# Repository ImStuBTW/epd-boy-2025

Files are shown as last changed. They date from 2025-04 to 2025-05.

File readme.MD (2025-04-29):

# EPD Boy (2025)

A work in progress ePaper laynard charm.

## Preview

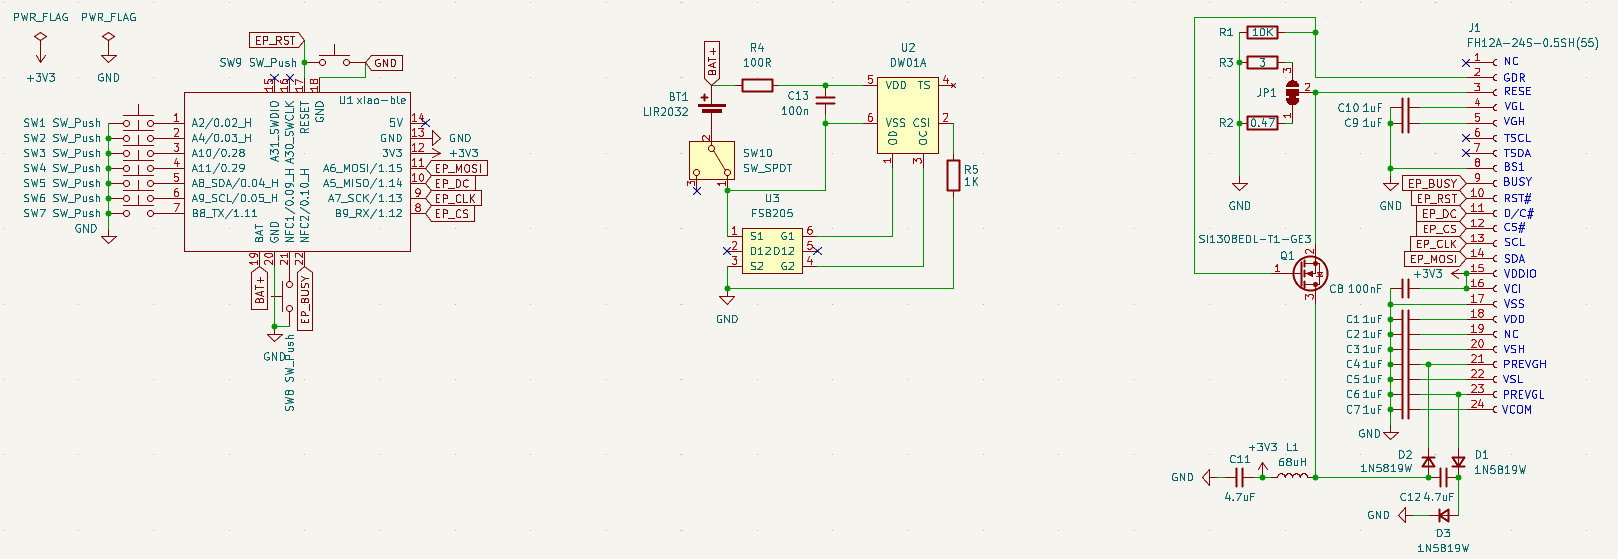
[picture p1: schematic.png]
Schematic

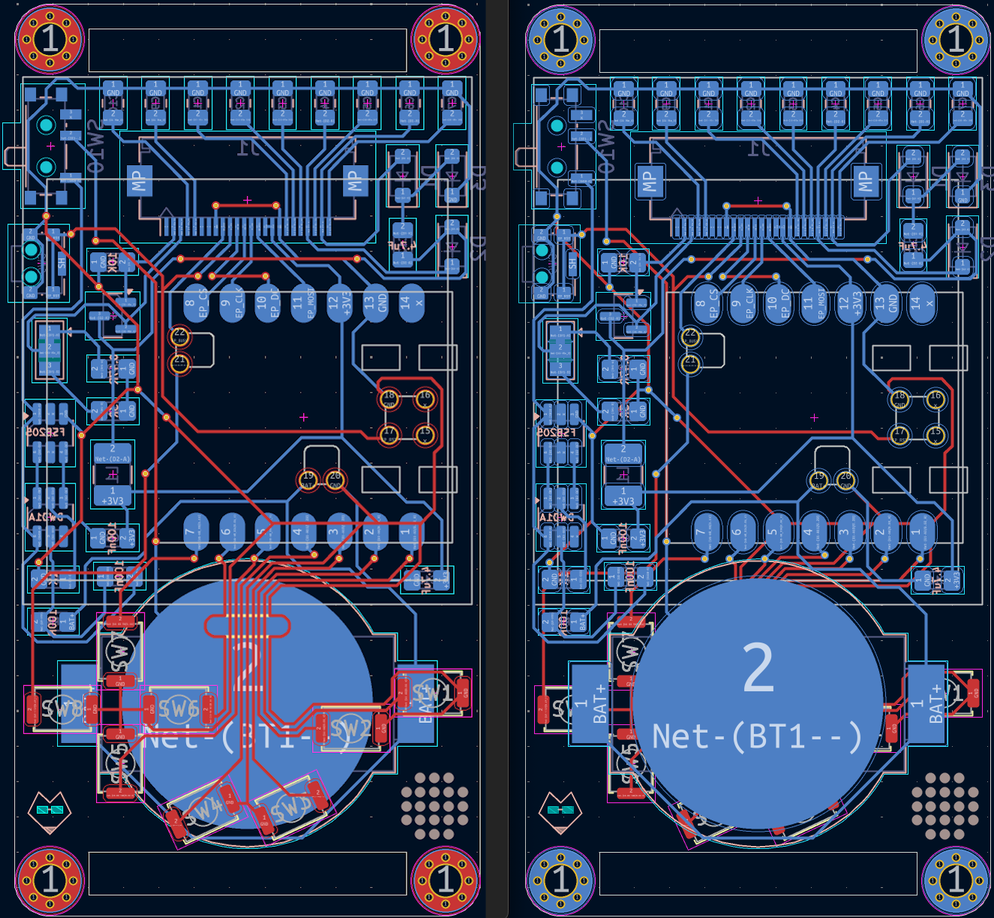
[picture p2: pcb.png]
PCB

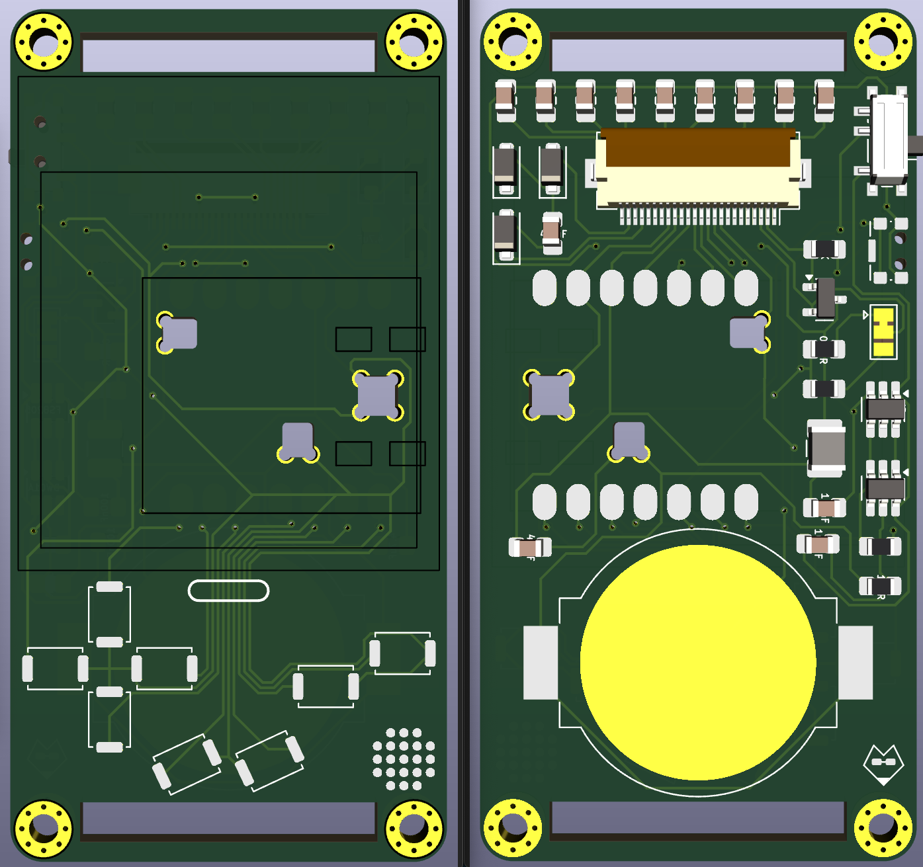
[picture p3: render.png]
Render


## References

Good Display: https://www.good-display.com/product/388.html

E-Ink Adapter: https://hackaday.io/project/164772-e-ink-adapter

Universal ePaper Display: https://www.pcbway.com/project/shareproject/Universal_E_Paper_adapter_PCB_9b9a845c.html

ZMK Design Guide (BMS Circuit Protection): https://github.com/ebastler/zmk-designguide?tab=readme-ov-file#additional-battery-management-considerations

BMS Footprints: https://github.com/ebastler/marbastlib

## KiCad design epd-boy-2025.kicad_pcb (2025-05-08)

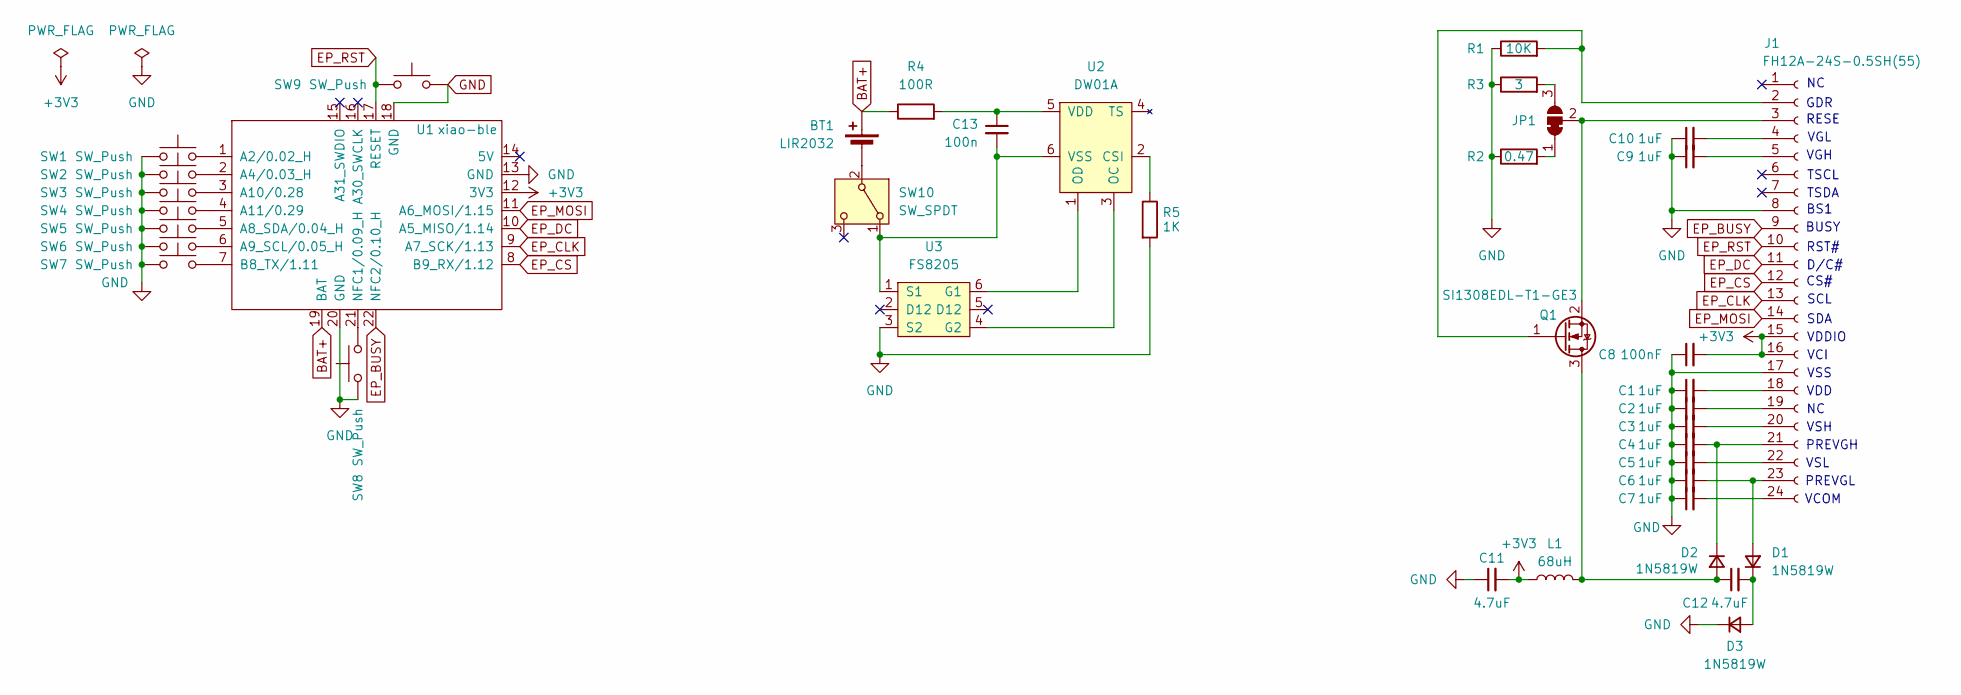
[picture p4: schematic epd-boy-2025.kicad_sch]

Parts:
BT1: LIR2032; BatteryHolder_MPD_BC2003_1x2032
C1, C2, C3, C4, C5, C6, C7, C9, C10: 1uF; C_0805_2012Metric_Pad1.18x1.45mm_HandSolder
C8: 100nF; C_0805_2012Metric_Pad1.18x1.45mm_HandSolder
C11, C12: 4.7uF; C_0805_2012Metric_Pad1.18x1.45mm_HandSolder
C13: 100n; C_0805_2012Metric_Pad1.18x1.45mm_HandSolder
D1, D2, D3: 1N5819W; D_SOD-123F
J1: FH12A-24S-0.5SH(55); Hirose_FH12-24S-0.5SH_1x24-1MP_P0.50mm_Horizontal
JP1: SolderJumper_3_Bridged12; SolderJumper-3_P1.3mm_Bridged12_Pad1.0x1.5mm
L1: 68uH; L_1210_3225Metric_Pad1.42x2.65mm_HandSolder
Q1: SI1308EDL-T1-GE3; SOT-23
R1: 10K; R_0805_2012Metric_Pad1.20x1.40mm_HandSolder
R2: 0.47; R_0805_2012Metric_Pad1.20x1.40mm_HandSolder
R3: 3; R_0805_2012Metric_Pad1.20x1.40mm_HandSolder
R4: 100R; R_0805_2012Metric_Pad1.20x1.40mm_HandSolder
R5: 1K; R_0805_2012Metric_Pad1.20x1.40mm_HandSolder
SW1, SW2, SW3, SW4, SW5, SW6, SW7, SW8: SW_Push; SW_Push_SPST_NO_Alps_SKRK
SW9: SW_Push; SW_SPST_CK_KMS2xxGP
SW10: SW_SPDT; SW_SPDT_PCM12
U1: xiao-ble; xiao-ble-smd-cutout-nfc
U2: DW01A; SOT-23-6_Handsoldering; LCSC C61503
U3: FS8205; SOT-23-6_Handsoldering; LCSC C32254

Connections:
+3V3: C8.2, C11.2, J1.15, J1.16, L1.1, U1.12 (3V3)
BAT+: BT1.1 (+), R4.1, U1.19 (BAT)
EP_BUSY: J1.9, U1.22 (NFC2/0.10_H)
EP_CLK: J1.13, U1.9 (A7_SCK/1.13)
EP_CS: J1.12, U1.8 (B9_RX/1.12)
EP_DC: J1.11, U1.10 (A5_MISO/1.14)
EP_MOSI: J1.14, U1.11 (A6_MOSI/1.15)
EP_RST: J1.10, SW9.1, U1.17 (RESET)
GND: C1.1, C2.1, C3.1, C4.1, C5.1, C6.1, C7.1, C8.1, C9.1, C10.1, C11.1, D3.1 (K), J1.8, J1.17, R1.1, R2.1, R3.1, R5.2, SW1.1, SW2.1, SW3.1, SW4.1, SW5.1, SW6.1, SW7.1, SW8.1, SW9.2, U1.13 (GND), U1.18 (GND), U1.20 (GND), U3.3 (S2)
unnamed: BT1.2 (-), SW10.2 (B)
unnamed: C6.2, D1.2 (A), J1.23
unnamed: C12.2, D1.1 (K), D3.2 (A)
unnamed: C12.1, D2.2 (A), L1.2, Q1.3 (D)
unnamed: C4.2, D2.1 (K), J1.21
unnamed: J1.2, Q1.1 (G), R1.2
unnamed: J1.3, JP1.2 (C), Q1.2 (S)
unnamed: C10.2, J1.4
unnamed: C9.2, J1.5
unnamed: C1.2, J1.18
unnamed: C2.2, J1.19
unnamed: C3.2, J1.20
unnamed: C5.2, J1.22
unnamed: C7.2, J1.24
unnamed: JP1.1 (A), R2.2
unnamed: JP1.3 (B), R3.2
unnamed: C13.2, SW10.1 (A), U2.6 (VSS), U3.1 (S1)
unnamed: SW1.2, U1.1 (A2/0.02_H)
unnamed: SW2.2, U1.2 (A4/0.03_H)
unnamed: SW5.2, U1.5 (A8_SDA/0.04_H)
unnamed: SW6.2, U1.6 (A9_SCL/0.05_H)
unnamed: SW3.2, U1.3 (A10/0.28)
unnamed: SW4.2, U1.4 (A11/0.29)
unnamed: SW7.2, U1.7 (B8_TX/1.11)
unnamed: SW8.2, U1.21 (NFC1/0.09_H)
unnamed: R5.1, U2.2 (CSI)
unnamed: U2.3 (OC), U3.4 (G2)
unnamed: U2.1 (OD), U3.6 (G1)
unnamed: C13.1, R4.2, U2.5 (VDD)

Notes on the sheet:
BS1
VCI
VSS
SCL
VCOM
VSL
BUSY
PREVGL
TSDA
D/C#
SDA
VDDIO
RST#
VGL
GDR
CS#
TSCL
PREVGH
VSH
RESE
VDD
VGH

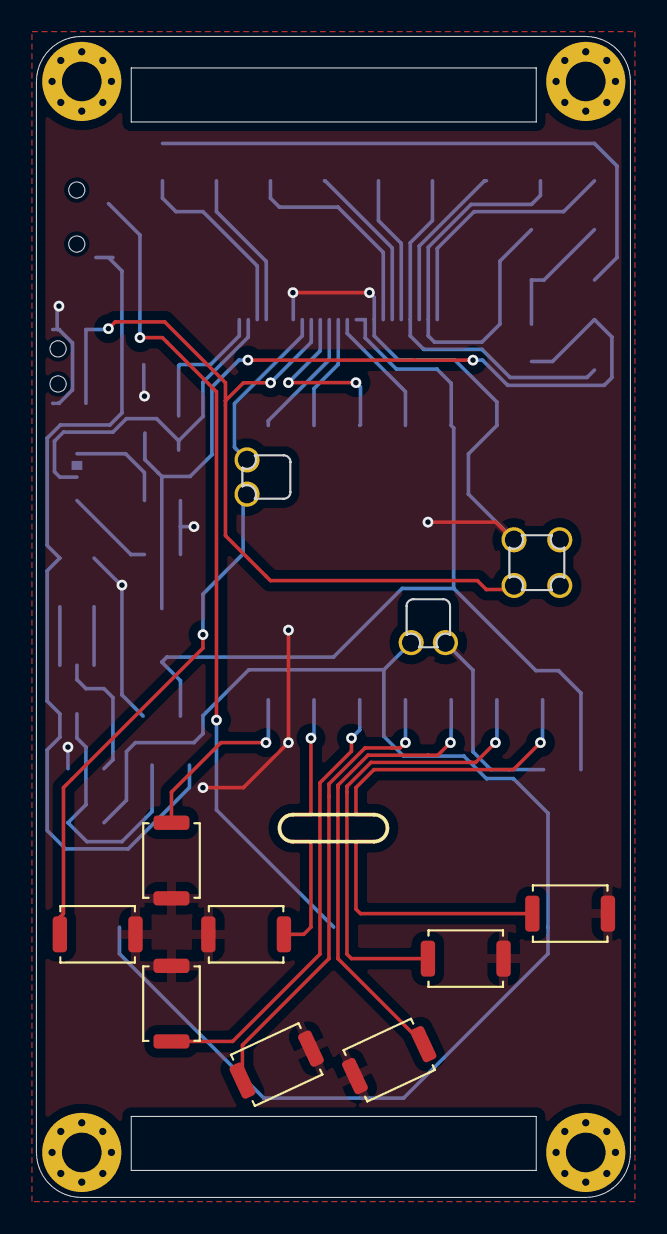
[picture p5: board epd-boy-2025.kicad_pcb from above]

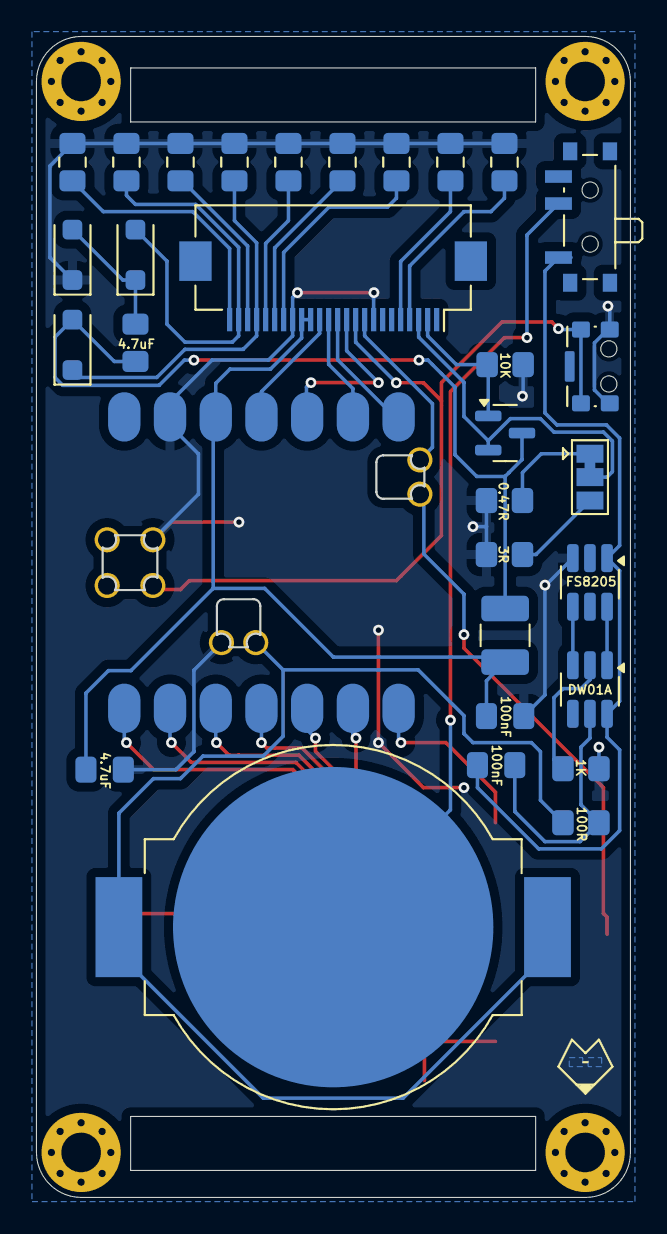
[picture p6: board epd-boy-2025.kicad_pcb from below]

Board: 2 copper layers, 33.0 x 64.5 mm, 39 parts (31 on the bottom side), 38 nets.
